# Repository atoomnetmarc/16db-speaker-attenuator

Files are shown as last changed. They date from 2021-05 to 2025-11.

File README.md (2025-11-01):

A simple resistive divider network to dampen the output of an audio amplifier 16db.

## The problem

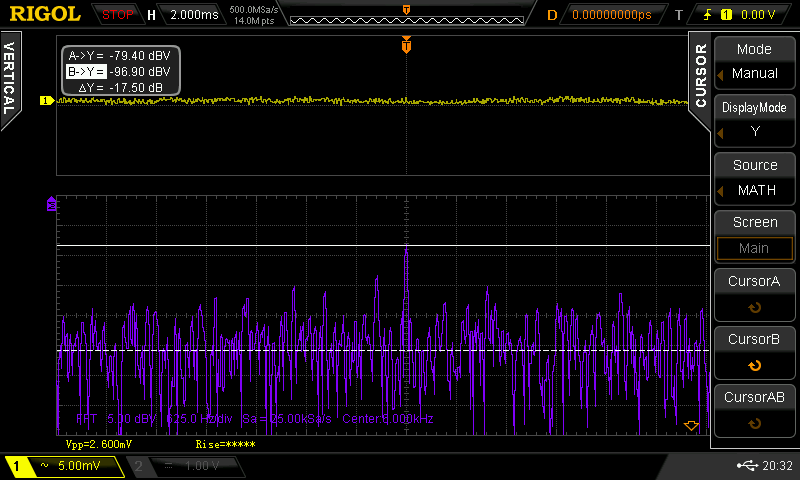
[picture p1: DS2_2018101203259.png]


See that spike at 6kHz? It was always there no matter what volume my Logitech Z-5500 Digital was set to. Very annoying.

The solution was this attenuator circuit that was fitted to each of the 5 channels of the amplifier. That peak at 6kHz is now 16db less annoying. Problem solved.

## Front

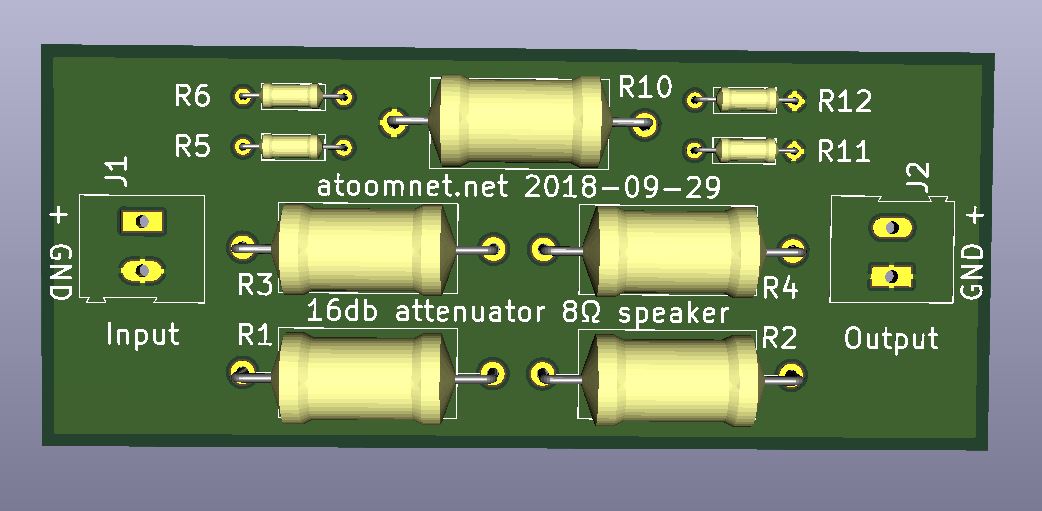
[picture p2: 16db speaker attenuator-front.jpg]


## Back

With instructions on how to tune the final resistor values.

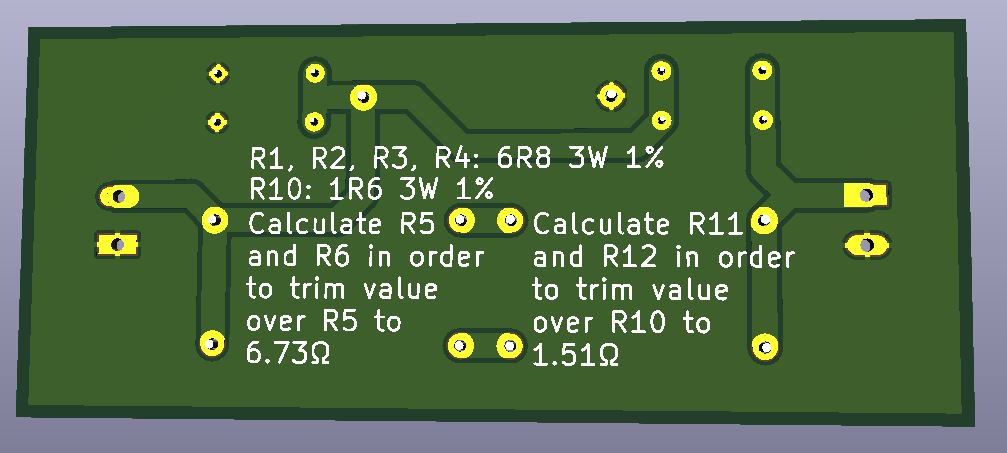
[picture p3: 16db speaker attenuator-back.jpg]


## 1/2 3d printable enclosure

Print 2, they fit together. There are slots in which the pcb's fit.

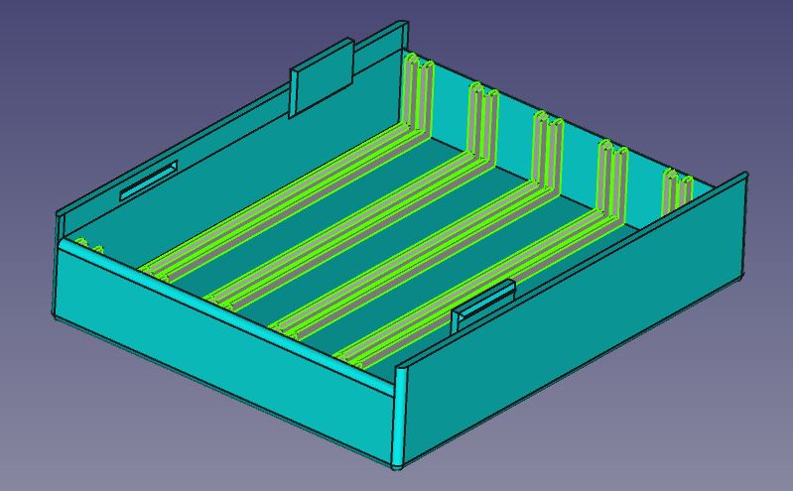
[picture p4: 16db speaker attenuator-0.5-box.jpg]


## The result

With 2 years of collected dust, but hey, it works :-)

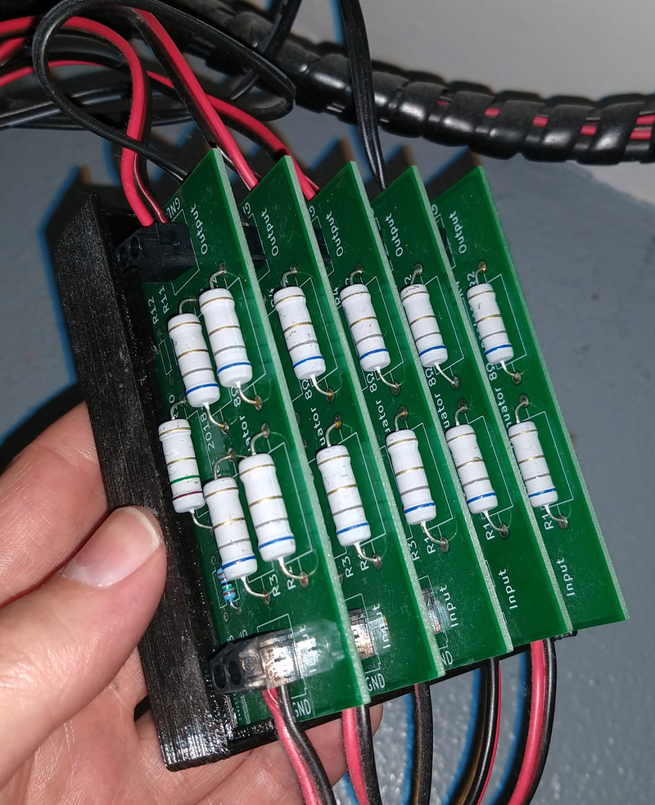
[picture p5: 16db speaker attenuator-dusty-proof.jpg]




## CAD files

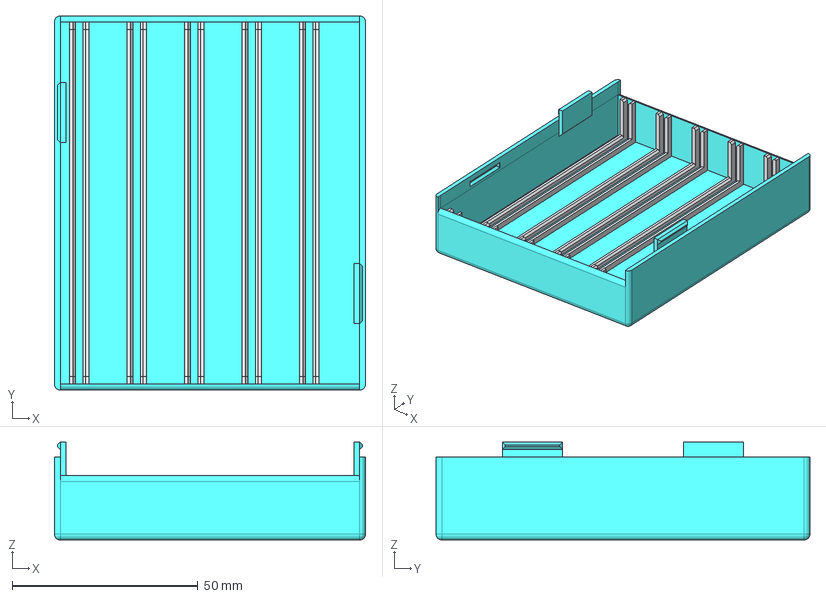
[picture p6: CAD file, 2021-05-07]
16db speaker attenuator pcb box.step
83.9 x 100.8 x 26.4 mm

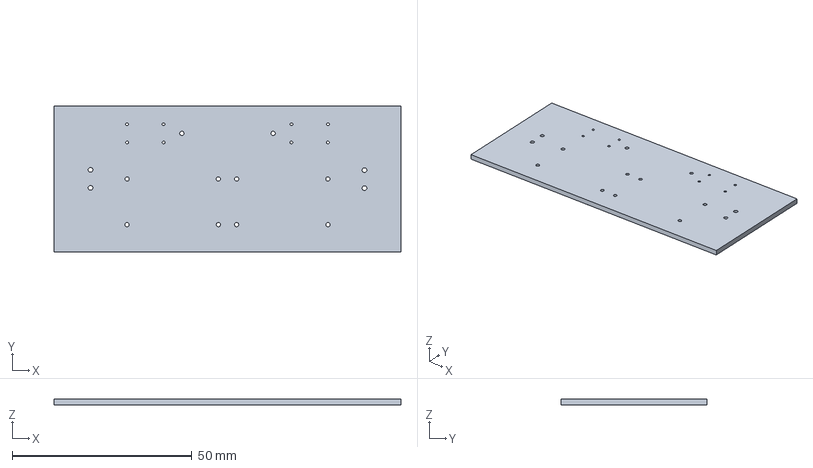
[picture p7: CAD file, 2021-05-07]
Kicad/16db attenuator.step
96.5 x 40.6 x 1.60 mm
R_Axial_DIN0918_L18.0mm_D9.0mm_P25.40mm_Horizontal x 5
R_Axial_DIN0207_L6.3mm_D2.5mm_P10.16mm_Horizontal x 4

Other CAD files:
16db speaker attenuator pcb box.FCStd
16db speaker attenuator pcb box.stl

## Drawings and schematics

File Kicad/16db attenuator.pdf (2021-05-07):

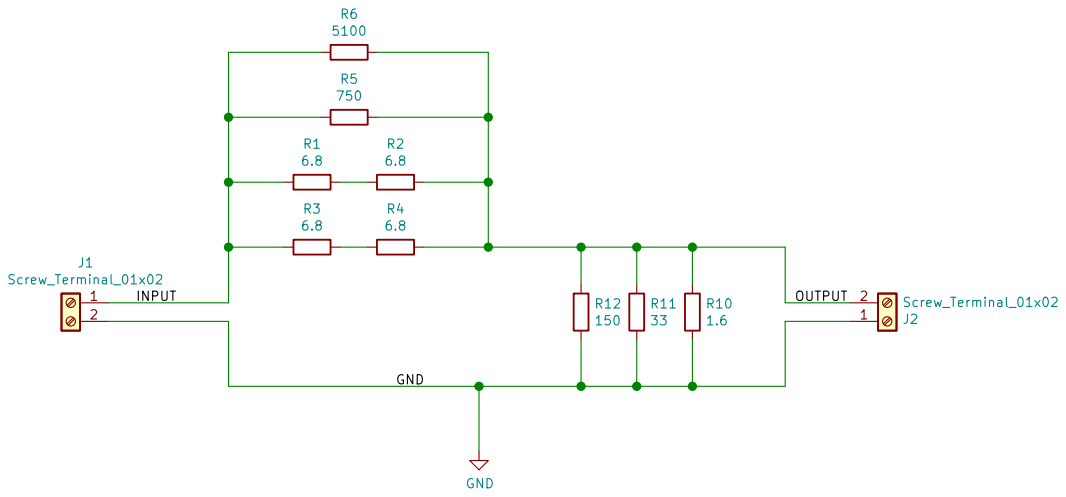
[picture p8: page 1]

Id: 1/1 Title: File: 16db attenuator.sch Sheet: /

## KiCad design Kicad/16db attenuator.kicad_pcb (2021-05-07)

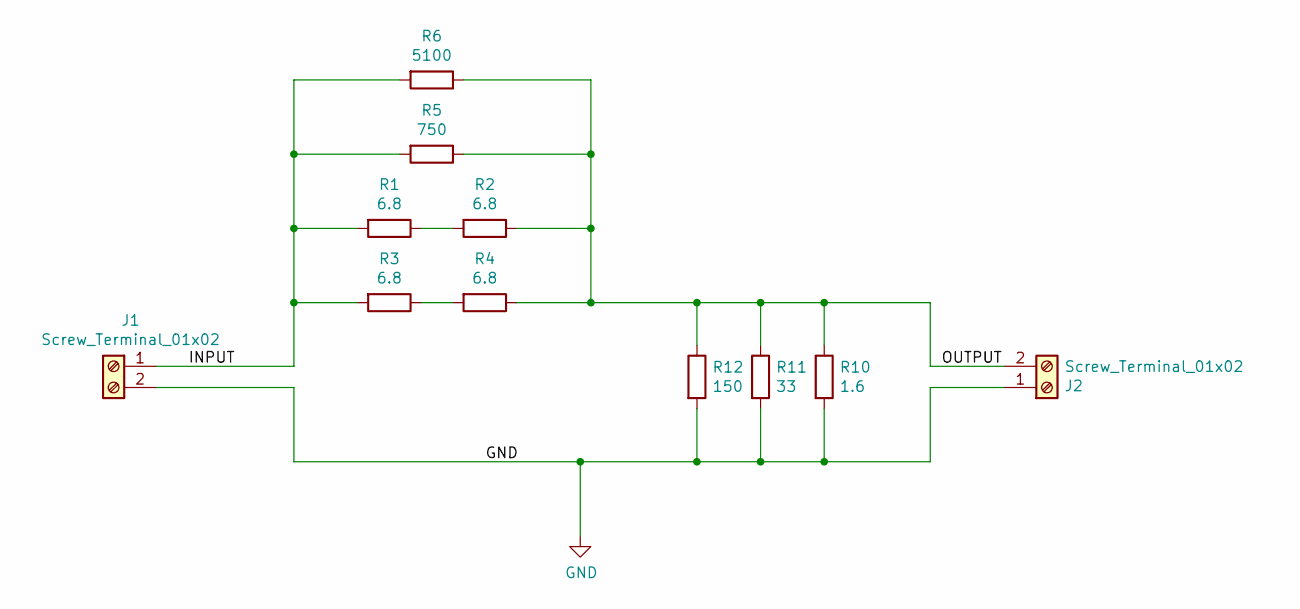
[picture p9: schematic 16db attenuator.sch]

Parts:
J1, J2: Screw_Terminal_01x02; TerminalBlock_Altech_AK300-2_P5.00mm
R1, R2, R3, R4: 6.8; R_Axial_DIN0918_L18.0mm_D9.0mm_P25.40mm_Horizontal
R5: 750; R_Axial_DIN0207_L6.3mm_D2.5mm_P10.16mm_Horizontal
R6: 5100; R_Axial_DIN0207_L6.3mm_D2.5mm_P10.16mm_Horizontal
R10: 1.6; R_Axial_DIN0918_L18.0mm_D9.0mm_P25.40mm_Horizontal
R11: 33; R_Axial_DIN0207_L6.3mm_D2.5mm_P10.16mm_Horizontal
R12: 150; R_Axial_DIN0207_L6.3mm_D2.5mm_P10.16mm_Horizontal

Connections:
/INPUT: J1.1, R1.2, R3.2, R5.2, R6.2
/OUTPUT: J2.2, R2.1, R4.1, R5.1, R6.1, R10.1, R11.1, R12.1
GND: J1.2, J2.1, R10.2, R11.2, R12.2
unnamed: R1.1, R2.2
unnamed: R3.1, R4.2

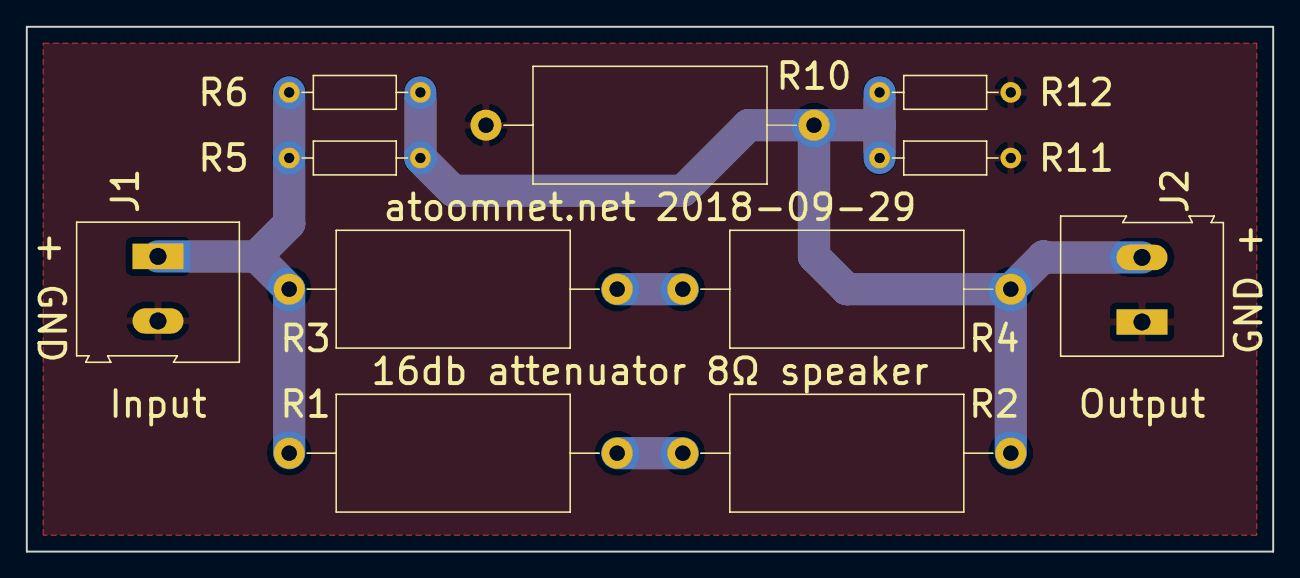
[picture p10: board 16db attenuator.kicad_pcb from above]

Board: 2 copper layers, 96.5 x 40.6 mm, 11 parts (0 on the bottom side), 5 nets.

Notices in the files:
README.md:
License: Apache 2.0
